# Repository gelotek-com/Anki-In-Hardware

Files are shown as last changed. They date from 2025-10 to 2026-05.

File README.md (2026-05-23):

# Physical Anki Device

Building a physical flashcard device inspired by **Anki** and **spaced repetition**.

## YouTube Series
Watch the full project here:  
🎥 https://www.youtube.com/playlist?list=PLZI8gkIZC2W3yhb4EUrMZ4vrkucjjzuon
## My website
My website for more details:
https://gelotek.com/AIH/

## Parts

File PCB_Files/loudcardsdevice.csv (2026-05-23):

Reference | Qty | Value | Footprint | Manufacturer | MPN | Supplier | Supplier Part
TP1,TP2,TP3,TP4,TP5,TP6,TP7,TP8,TP9,TP10,TP11 | 11 | TestPoint | TestPoint:TestPoint_Pad_1.0x1.0mm
C1,C2,C5,C6,C8,C9,C10,C15,C27,C29 | 10 | 0.1u | Capacitor_SMD:C_0603_1608Metric | Walsin | 0603B104K250CT | LCSC | C83054
U5 | 1 | AMS1117-3.3 | Package_TO_SOT_SMD:SOT-223-3_TabPin2 | Advanced Monolithic Systems | AMS1117-3.3 | LCSC | C6186
U1 | 1 | ESP32-C3-WROOM-02 | RF_Module:ESP32-C3-WROOM-02 | ESPRESSIF | ESP32-C3-WROOM-02-H4 | LCSC | C2944070
R5,R14,R15,R22,R23,R24 | 6 | 5.1k | Resistor_SMD:R_0603_1608Metric | FOJAN | FRC0603F5101TS | LCSC | C2907044
J3 | 1 | USB_C_Receptacle_PowerOnly_6P | Connector_USB:USB_C_Receptacle_GCT_USB4125-xx-x-0190_6P_TopMnt_Horizontal | GCT | USB4125-GF-A-0190 | LCSC | C5246813
FB1 | 1 | 600Ω @ 100MHzSize 0805 preferred for audio rails. | Inductor_SMD:L_0805_2012Metric | muRata | BLM21PG221SN1D | LCSC | C85840
C3,C19,C20,C21,C22,C24,C25 | 7 | 1u | Capacitor_SMD:C_0603_1608Metric | Samsung Electro-Mechanics | CL10A105KO8NNNC | LCSC | C1592
C4,C7,C13,C14,C17,C26,C28 | 7 | 10u | Capacitor_SMD:C_0603_1608Metric | Samsung Electro-Mechanics | CL10A106MQ8NNNC | LCSC | C1691
C11,C12,C23 | 3 | 2.2u | Capacitor_SMD:C_0603_1608Metric | Samsung Electro-Mechanics | CL10A225KQ8NNNC | LCSC | C71000
D5 | 1 | TVS 5V ESD Protection | Diode_SMD:D_SOD-323F | SEMTECH | SD05.TCT | LCSC | C85201
J2 | 1 | AudioJack4 | Connector_Audio:Jack_3.5mm_PJ320D_Horizontal | SHOU HAN | PJ-320D | LCSC | C431535
SW1,SW2,SW3,SW4,SW5 | 5 | SW_Push | Button_Switch_THT:SW_PUSH_6mm | SHOU HAN | TS665CJ | LCSC | C393938
U3 | 1 | PCM5102A | Package_SO:TSSOP-20_4.4x6.5mm_P0.65mm | TI | PCM5102APWR | LCSC | C107671
U4 | 1 | TPA6132A2RTE | Package_DFN_QFN:WQFN-16-1EP_3x3mm_P0.5mm_EP1.6x1.6mm_ThermalVias | TI | TPA6132A2RTER | LCSC | C69901
R19,R20 | 2 | 470 | Resistor_SMD:R_0603_1608Metric | UNI-ROYAL | 0603WAF4700T5E | LCSC | C23179
C16,C18 | 2 | 2.2n | Capacitor_SMD:C_0603_1608Metric | Walsin | 0603B222K500CT | LCSC | C93190
U2 | 1 | W25Q128JVS | Package_SO:SOIC-8_5.3x5.3mm_P1.27mm | Winbond | W25Q128JVSIQ | LCSC | C97521
J1 | 1 | Conn_01x04 | Connector_PinHeader_2.54mm:PinHeader_1x04_P2.54mm_Vertical | XFCN | PZ254V-11-04P | LCSC | C2691448
R1,R2,R3,R4,R10,R11,R12 | 7 | 10k | Resistor_SMD:R_0603_1608Metric | YAGEO | RC0603FR-0710KL | LCSC | C98220
R6,R7,R8,R9 | 4 | 50 | Resistor_SMD:R_0603_1608Metric | YAGEO | RT0603BRE0750RL | LCSC | C849792
R13,R21 | 2 | 100k | Resistor_SMD:R_0603_1608Metric | YAGEO | RC0603FR-07100KL | LCSC | C14675
R16,R17,R18 | 3 | 22 | Resistor_SMD:R_0603_1608Metric | YAGEO | RC0603FR-0722RL | LCSC | C107701
D1,D2,D3,D4 | 4 | LED | LED_SMD:LED_0603_1608Metric | YONGYUTAI | YLED0603R | LCSC | C19171390

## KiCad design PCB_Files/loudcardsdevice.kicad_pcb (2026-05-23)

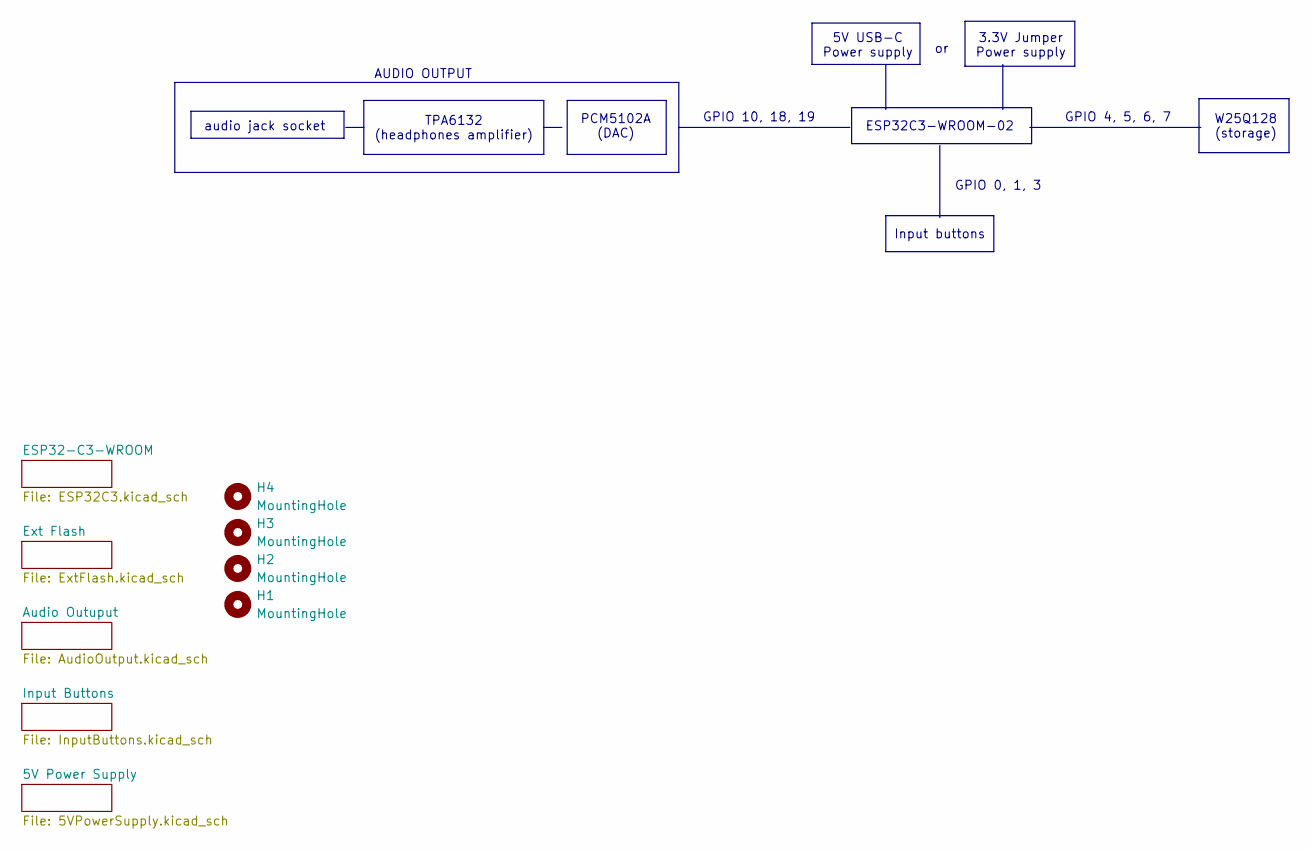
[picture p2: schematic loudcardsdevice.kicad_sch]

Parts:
H1, H2, H3, H4: MountingHole; MountingHole_2.1mm

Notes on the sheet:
ESP32C3-WROOM-02
GPIO 10, 18, 19
PCM5102A (DAC)
3.3V Jumper Power supply
GPIO 0, 1, 3
5V USB-C Power supply
AUDIO OUTPUT
TPA6132 (headphones amplifier)
Input buttons
W25Q128 (storage)
GPIO 4, 5, 6, 7
audio jack socket

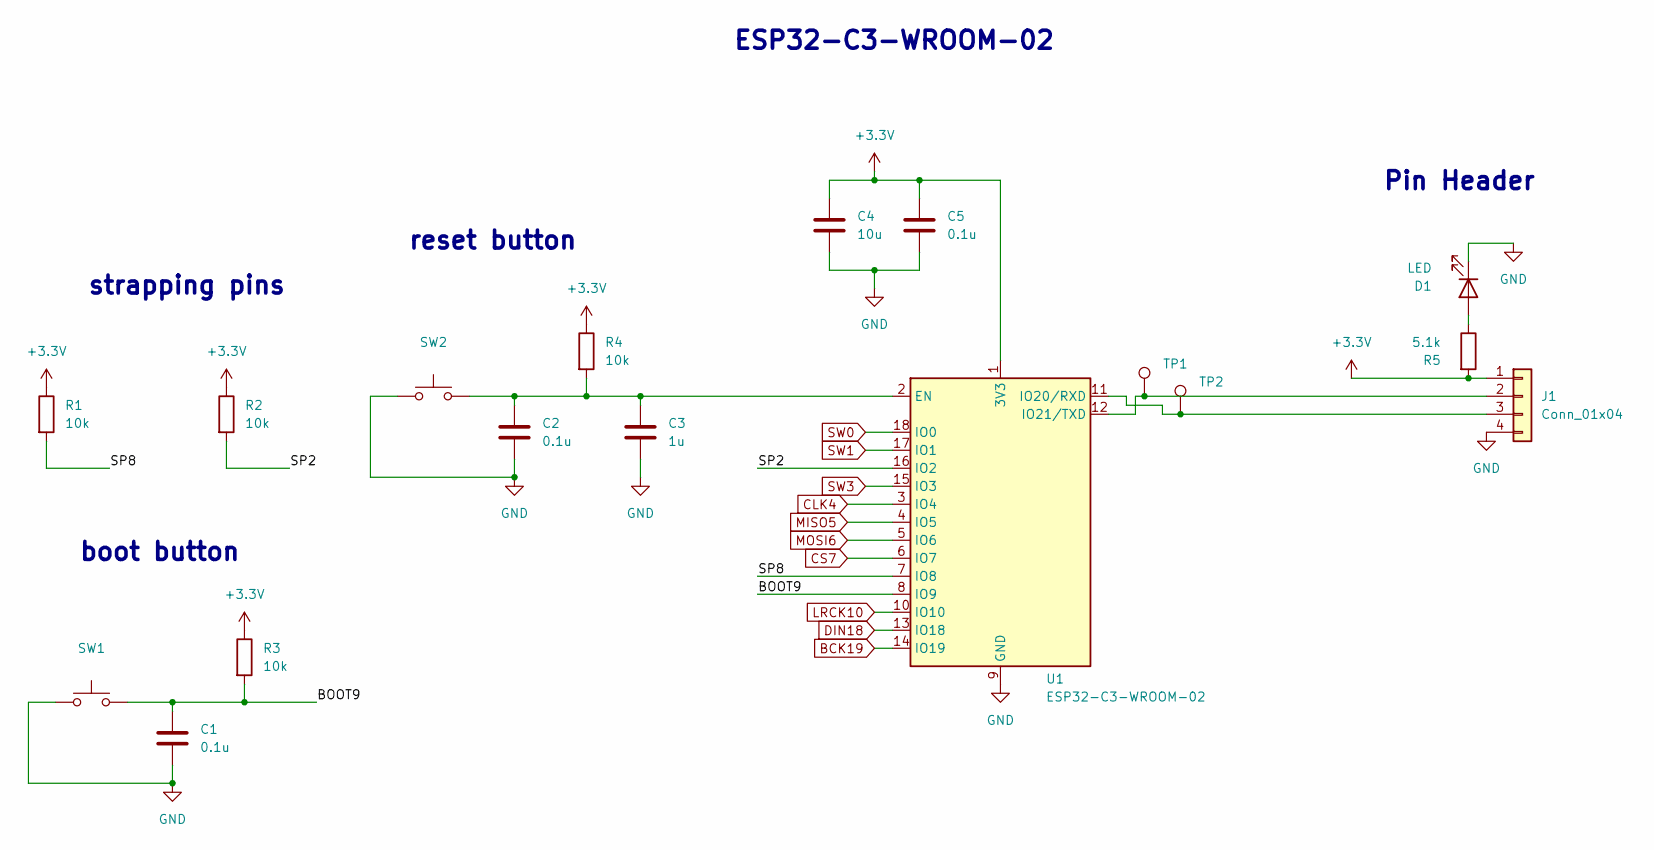
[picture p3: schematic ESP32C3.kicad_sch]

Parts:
C1, C2, C5: 0.1u; C_0603_1608Metric; MPN 0603B104K250CT
C3: 1u; C_0603_1608Metric; MPN CL10A105KO8NNNC
C4: 10u; C_0603_1608Metric; MPN CL10A106MQ8NNNC
D1: LED; LED_0603_1608Metric; MPN YLED0603R
J1: Conn_01x04; PinHeader_1x04_P2.54mm_Vertical; MPN PZ254V-11-04P
R1, R2, R3, R4: 10k; R_0603_1608Metric; MPN RC0603FR-0710KL
R5: 5.1k; R_0603_1608Metric; MPN FRC0603F5101TS
SW1, SW2: SW_Push; SW_PUSH_6mm; MPN TS665CJ
TP1, TP2: TestPoint; TestPoint_Pad_1.0x1.0mm
U1: ESP32-C3-WROOM-02; MPN ESP32-C3-WROOM-02-H4

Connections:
+3.3V: C4.1, C5.1, J1.1, R1.1, R2.1, R3.1, R4.1, R5.2, U1.1 (3V3); also elsewhere on the board
/ESP32-C3-WROOM/BOOT9: C1.1, R3.2, SW1.2, U1.8 (IO9)
/ESP32-C3-WROOM/SP2: R2.2, U1.16 (IO2)
/ESP32-C3-WROOM/SP8: R1.2, U1.7 (IO8)
BCK19: U1.14 (IO19); also elsewhere on the board
CLK4: U1.3 (IO4); also elsewhere on the board
CS7: U1.6 (IO7); also elsewhere on the board
DIN18: U1.13 (IO18); also elsewhere on the board
GND: C1.2, C2.2, C3.2, C4.2, C5.2, D1.1 (K), J1.4, SW1.1, SW2.1, U1.9 (GND), U1.19 (GND); also elsewhere on the board
LRCK10: U1.10 (IO10); also elsewhere on the board
MISO5: U1.4 (IO5); also elsewhere on the board
MOSI6: U1.5 (IO6); also elsewhere on the board
unnamed: D1.2 (A), R5.1
unnamed: J1.2, TP1.1, U1.12 (IO21/TXD)
unnamed: J1.3, TP2.1, U1.11 (IO20/RXD)
unnamed: C2.1, C3.1, R4.2, SW2.2, U1.2 (EN)
SW0: U1.18 (IO0); also elsewhere on the board
SW1: U1.17 (IO1); also elsewhere on the board
SW3: U1.15 (IO3); also elsewhere on the board

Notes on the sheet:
strapping pins
boot button
Pin Header
reset button
ESP32-C3-WROOM-02

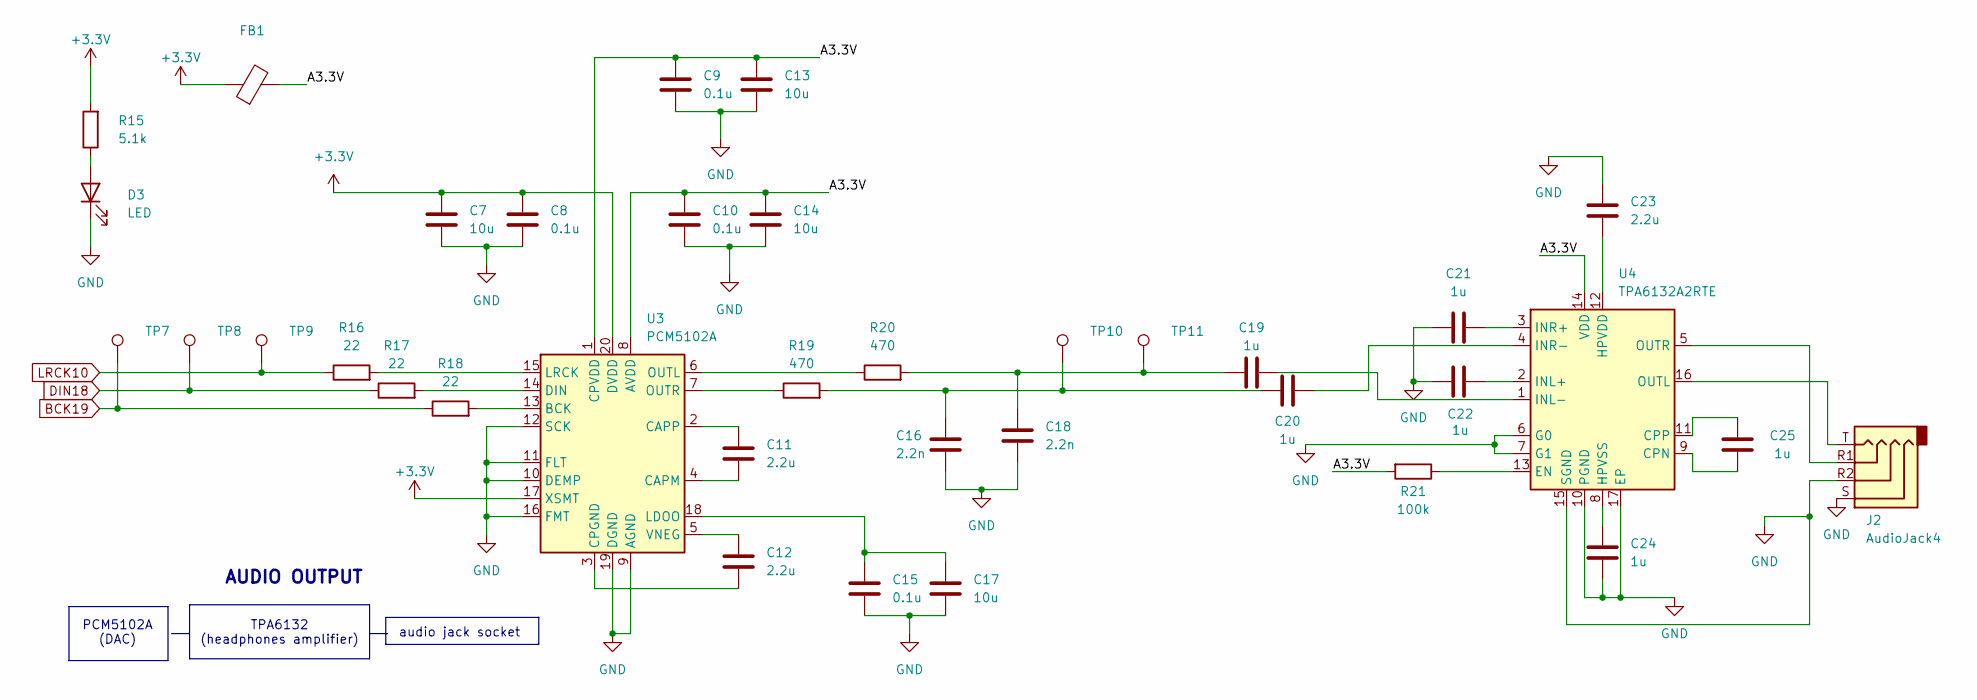
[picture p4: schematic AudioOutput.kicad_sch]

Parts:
C7, C13, C14, C17: 10u; C_0603_1608Metric; MPN CL10A106MQ8NNNC
C8, C9, C10, C15: 0.1u; C_0603_1608Metric; MPN 0603B104K250CT
C11, C12, C23: 2.2u; C_0603_1608Metric; MPN CL10A225KQ8NNNC
C16, C18: 2.2n; C_0603_1608Metric; MPN 0603B222K500CT
C19, C20, C21, C22, C24, C25: 1u; C_0603_1608Metric; MPN CL10A105KO8NNNC
D3: LED; LED_0603_1608Metric; MPN YLED0603R
FB1: 600Ω @ 100MHzSize 0805 preferred for audio rails.; L_0805_2012Metric; MPN BLM21PG221SN1D
J2: AudioJack4; Jack_3.5mm_PJ320D_Horizontal; MPN PJ-320D
R15: 5.1k; R_0603_1608Metric; MPN FRC0603F5101TS
R16, R17, R18: 22; R_0603_1608Metric; MPN RC0603FR-0722RL
R19, R20: 470; R_0603_1608Metric; MPN 0603WAF4700T5E
R21: 100k; R_0603_1608Metric; MPN RC0603FR-07100KL
TP7, TP8, TP9, TP10, TP11: TestPoint; TestPoint_Pad_1.0x1.0mm
U3: PCM5102A; TSSOP-20_4.4x6.5mm_P0.65mm; MPN PCM5102APWR
U4: TPA6132A2RTE; WQFN-16-1EP_3x3mm_P0.5mm_EP1.6x1.6mm_ThermalVias; MPN TPA6132A2RTER

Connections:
+3.3V: C7.1, C8.1, FB1.1, R15.2, U3.17 (XSMT), U3.20 (DVDD); also elsewhere on the board
/Audio Outuput/A3.3V: C9.1, C10.1, C13.1, C14.1, FB1.2, R21.2, U3.1 (CPVDD), U3.8 (AVDD), U4.14 (VDD)
BCK19: R18.1, TP7.1; also elsewhere on the board
DIN18: R17.1, TP8.1; also elsewhere on the board
GND: C7.2, C8.2, C9.2, C10.2, C13.2, C14.2, C15.2, C16.2, C17.2, C18.2, C21.1, C22.1, C23.2, C24.1, D3.1 (K), J2.R2, J2.S, U3.9 (AGND), U3.10 (DEMP), U3.11 (FLT), U3.12 (SCK), U3.16 (FMT), U3.19 (DGND), U4.6 (G0), U4.7 (G1), U4.10 (PGND), U4.15 (SGND), U4.17 (EP); also elsewhere on the board
LRCK10: R16.1, TP9.1; also elsewhere on the board
unnamed: C16.1, C20.1, R19.2, TP10.1
unnamed: C18.1, C19.1, R20.2, TP11.1
unnamed: D3.2 (A), R15.1
unnamed: R18.2, U3.13 (BCK)
unnamed: C11.2, U3.4 (CAPM)
unnamed: C11.1, U3.2 (CAPP)
unnamed: C12.2, U3.3 (CPGND)
unnamed: R17.2, U3.14 (DIN)
unnamed: C15.1, C17.1, U3.18 (LDOO)
unnamed: R16.2, U3.15 (LRCK)
unnamed: R20.1, U3.6 (OUTL)
unnamed: R19.1, U3.7 (OUTR)
unnamed: C12.1, U3.5 (VNEG)
unnamed: C25.2, U4.9 (CPN)
unnamed: C25.1, U4.11 (CPP)
unnamed: R21.1, U4.13 (EN)
unnamed: C23.1, U4.12 (HPVDD)
unnamed: C24.2, U4.8 (HPVSS)
unnamed: C22.2, U4.2 (INL+)
unnamed: C19.2, U4.1 (INL-)
unnamed: C21.2, U4.3 (INR+)
unnamed: C20.2, U4.4 (INR-)
unnamed: J2.T, U4.16 (OUTL)
unnamed: J2.R1, U4.5 (OUTR)

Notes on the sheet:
audio jack socket
PCM5102A (DAC)
TPA6132 (headphones amplifier)
AUDIO OUTPUT

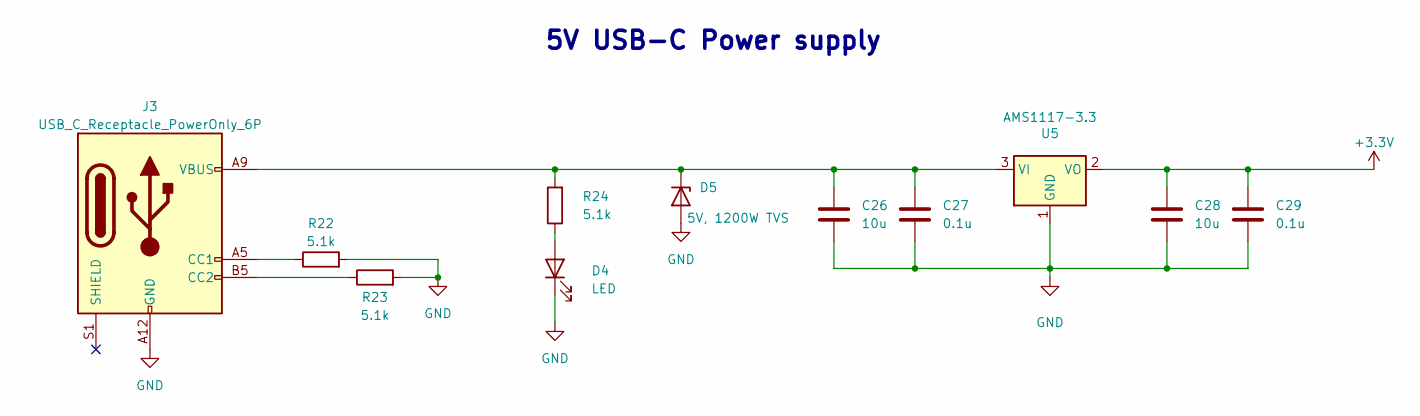
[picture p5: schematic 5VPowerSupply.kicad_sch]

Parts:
C26, C28: 10u; C_0603_1608Metric; MPN CL10A106MQ8NNNC
C27, C29: 0.1u; C_0603_1608Metric
D4: LED; LED_0603_1608Metric; MPN YLED0603R
D5: 5V, 1200W TVS; D_SOD-323F; MPN SD05.TCT
J3: USB_C_Receptacle_PowerOnly_6P; USB_C_Receptacle_GCT_USB4125-xx-x-0190_6P_TopMnt_Horizontal; MPN USB4125-GF-A-0190
R22, R23, R24: 5.1k; R_0603_1608Metric; MPN FRC0603F5101TS
U5: AMS1117-3.3; SOT-223-3_TabPin2; MPN AMS1117-3.3

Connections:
+3.3V: C28.1, C29.1, U5.2 (VO); also elsewhere on the board
GND: C26.2, C27.2, C28.2, C29.2, D4.1 (K), D5.2 (A), J3.A12 (GND), J3.B12 (GND), R22.2, R23.2, U5.1 (GND); also elsewhere on the board
unnamed: D4.2 (A), R24.1
unnamed: C26.1, C27.1, D5.1 (K), J3.A9 (VBUS), J3.B9 (VBUS), R24.2, U5.3 (VI)
unnamed: J3.A5 (CC1), R22.1
unnamed: J3.B5 (CC2), R23.1

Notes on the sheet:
5V USB-C Power supply

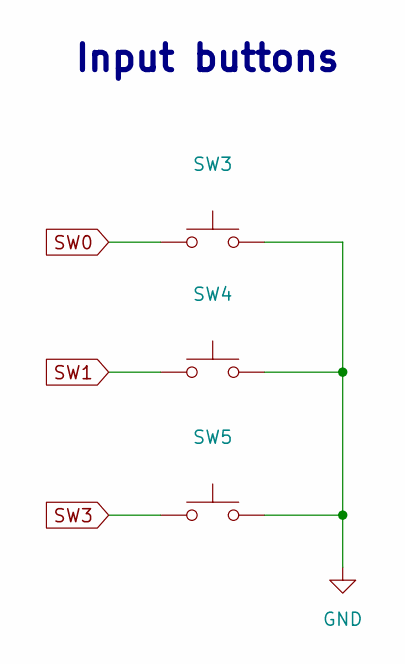
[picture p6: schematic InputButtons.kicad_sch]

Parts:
SW3, SW4, SW5: SW_Push; SW_PUSH_6mm; MPN TS665CJ

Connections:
GND: SW3.2, SW4.2, SW5.2; also elsewhere on the board
SW0: SW3.1; also elsewhere on the board
SW1: SW4.1; also elsewhere on the board
SW3: SW5.1; also elsewhere on the board

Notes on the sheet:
Input buttons

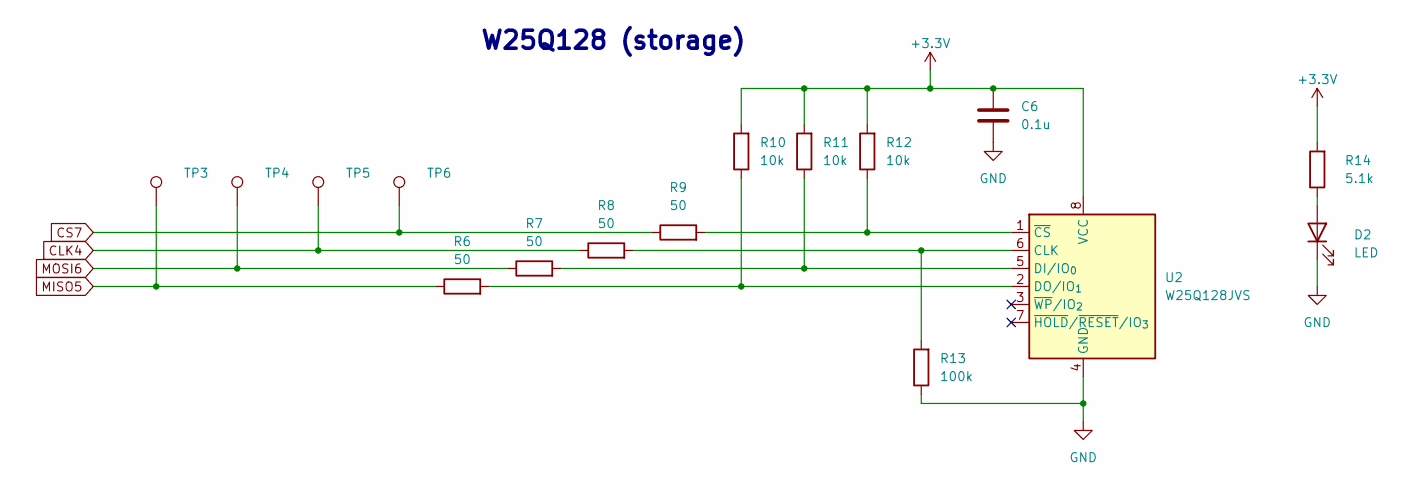
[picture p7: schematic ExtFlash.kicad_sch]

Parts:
C6: 0.1u; C_0603_1608Metric; MPN 0603B104K250CT
D2: LED; LED_0603_1608Metric; MPN YLED0603R
R6, R7, R8, R9: 50; R_0603_1608Metric; MPN RT0603BRE0750RL
R10, R11, R12: 10k; R_0603_1608Metric; MPN RC0603FR-0710KL
R13: 100k; R_0603_1608Metric; MPN RC0603FR-07100KL
R14: 5.1k; R_0603_1608Metric; MPN FRC0603F5101TS
TP3, TP4, TP5, TP6: TestPoint; TestPoint_Pad_1.0x1.0mm
U2: W25Q128JVS; SOIC-8_5.3x5.3mm_P1.27mm; MPN W25Q128JVSIQ

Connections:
+3.3V: C6.1, R10.2, R11.2, R12.2, R14.2, U2.8 (VCC); also elsewhere on the board
CLK4: R8.1, TP5.1; also elsewhere on the board
CS7: R9.1, TP6.1; also elsewhere on the board
GND: C6.2, D2.1 (K), R13.1, U2.4 (GND); also elsewhere on the board
MISO5: R6.1, TP3.1; also elsewhere on the board
MOSI6: R7.1, TP4.1; also elsewhere on the board
unnamed: D2.2 (A), R14.1
unnamed: R8.2, R13.2, U2.6 (CLK)
unnamed: R7.2, R11.1, U2.5 (DI/IO_{0})
unnamed: R6.2, R10.1, U2.2 (DO/IO_{1})
unnamed: R9.2, R12.1, U2.1 (~CS)

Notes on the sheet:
W25Q128 (storage)

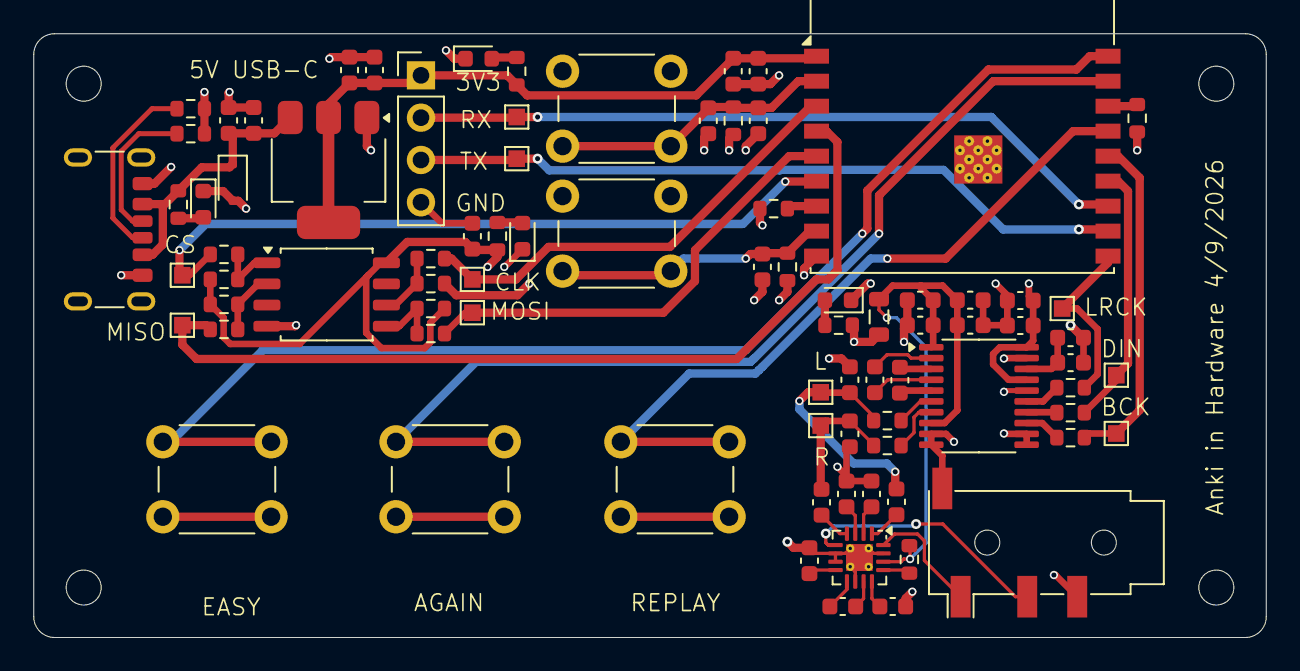
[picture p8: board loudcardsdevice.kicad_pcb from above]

Board: 4 copper layers, 74.0 x 36.2 mm, 87 parts (0 on the bottom side), 53 nets.

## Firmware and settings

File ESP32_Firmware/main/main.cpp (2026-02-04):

#include <stdio.h>
#include <string>

#include "freertos/FreeRTOS.h"
#include "freertos/task.h"

#include "esp_log.h"
#include "nvs_flash.h"

#include "driver/gpio.h"

#include <ArduinoJson.h>

#include "wifi_setup.h"
#include "setup_buttons.h"
#include "http_setup.h"
#include "audio_setup.h"
#include "ext_flash.h"

static const char *TAG = "MAIN";


extern "C" void app_main(void)
{
    // Initialize NVS (required for WiFi, HTTP, etc.)
    esp_err_t ret = nvs_flash_init();
    if (ret == ESP_ERR_NVS_NO_FREE_PAGES || ret == ESP_ERR_NVS_NEW_VERSION_FOUND) {
        nvs_flash_erase();
        nvs_flash_init();
    }

    ESP_LOGI(TAG, "System starting");

    // Hardware setup
    setupButtons();

    vTaskDelay(pdMS_TO_TICKS(1000));

    setupAudio(); // setup audio  + extflash
    setupWiFi();

    /*
    clearIntFiles();

    vTaskDelay(pdMS_TO_TICKS(1000));

    DownloadSpecificAudio("/response.wav");
    DownloadSpecificAudio("/start.wav");
    DownloadSpecificAudio("/clear.wav");
    DownloadSpecificAudio("/download.wav");
    DownloadSpecificAudio("/downloading.wav");
    DownloadSpecificAudio("/end.wav");
    */

    // Startup audio
    playAudio("/start.wav", "/littlefs");
    playAudio("/response.wav", "/littlefs");

    // Wait for user action
    waitForButton("Press YELLOW to start or BLUE to download the audio files");

    // Get cards from server
    std::string cardData = HTTPboot();

    // JSON for HTTP output
    JsonDocument easeDoc;
    JsonArray easeArray = easeDoc["results"].to<JsonArray>();

    // JSON for FlashCards
    JsonDocument doc;
    DeserializationError err = deserializeJson(doc, cardData);
    if (err) {
        ESP_LOGE(TAG, "JSON parse failed: %s", err.c_str());
        return;
    }

    JsonArray cards = doc["cards"].as<JsonArray>();

    // Download all audio files
    downloadAllAudio_ext(cards);

    playAudio("/download.wav", "/littlefs");

    // Study session
    for (JsonObject card : cards) {
        int64_t cardId = card["id"].as<long long>();
        std::string front = card["front"].as<std::string>();
        std::string back  = card["back"].as<std::string>();

        if (checkAudioFiles_ext(cardId)) {
            ESP_LOGI(TAG, "---- Next card ----");
            ESP_LOGI(TAG, "Front: %s", front.c_str());

            // Front
            ESP_LOGI(TAG, "Press START to see the back.");
            playFrontAudio(button3Pin, button1Pin, cardId);

            // Back
            ESP_LOGI(TAG, "Back: %s", back.c_str());
            ESP_LOGI(TAG, "Decide");

            int ease = playBackAudio(
                button1Pin,
                button2Pin,
                button3Pin,
                cardId
            );

            // Store result
            JsonObject r = easeArray.add<JsonObject>();
            r["card_id"] = cardId;
            r["ease"] = ease;
        }
    }

    // Send results back
    std::string jsonOut;
    serializeJson(easeDoc, jsonOut);

    ESP_LOGI(TAG, "Result JSON: %s", jsonOut.c_str());
    HTTPout(jsonOut);

    // Session complete
    playAudio("/end.wav", "/littlefs");
    ESP_LOGI(TAG, "Study session complete.");


    // app_main should not exit
    while (true) {
        vTaskDelay(pdMS_TO_TICKS(1000));
    }
}

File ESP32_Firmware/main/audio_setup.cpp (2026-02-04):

#include "audio_setup.h"
#include "ext_flash.h"

#include <stdint.h>
#include <stdlib.h>
#include <stdio.h>
#include <string>

#include "freertos/FreeRTOS.h"
#include "freertos/task.h"

#include "esp_log.h"
//#include "esp_vfs_littlefs.h"
#include "esp_vfs.h"
#include "esp_littlefs.h"

//#include "driver/ledc.h"
#include "driver/gpio.h"
#include "esp_rom_sys.h"

#include "driver/i2s_std.h"


#define EXAMPLE_STD_BCLK_IO1   GPIO_NUM_21
#define EXAMPLE_STD_WS_IO1     GPIO_NUM_10
#define EXAMPLE_STD_DOUT_IO1   GPIO_NUM_20
#define EXAMPLE_STD_DIN_IO1    GPIO_NUM_NC

#define EXAMPLE_BUFF_SIZE               2048
static i2s_chan_handle_t                tx_chan; 

static const char *TAG = "AUDIO";


void playAudio(const std::string &path, const std::string &storage)
{
    //printf("Playback started\n");
    std::string fullPath = storage + path;
    FILE *f = fopen(fullPath.c_str(), "rb");
    if (!f) {
        printf("Failed to open audio file\n");
        vTaskDelete(NULL);
        return;
    }

    fseek(f, 44, SEEK_SET);

    uint8_t *buf = (uint8_t *)malloc(EXAMPLE_BUFF_SIZE);
    if (!buf) {
        fclose(f);
        vTaskDelete(NULL);
        return;
    }

    ESP_ERROR_CHECK(i2s_channel_enable(tx_chan));

    size_t bytes_read = 0;
    
    while ((bytes_read = fread(buf, 1, EXAMPLE_BUFF_SIZE, f)) > 0) {
        //printf("Read %d bytes\n", bytes_read);
        size_t written = 0;
        esp_err_t err = i2s_channel_write(tx_chan, buf, bytes_read, &written, portMAX_DELAY);
        //printf("Written %d bytes\n", written);
        if (err != ESP_OK) {
            printf("I2S write failed: %d\n", err);
            break;
        }
    }

    //printf("Playback finished\n");
    i2s_channel_disable(tx_chan);
    free(buf);
    fclose(f);
    ESP_LOGI(TAG, "Done playing: %s", path.c_str());
}

void i2s_example_init_std_simplex(void)
{
    i2s_chan_config_t tx_chan_cfg = I2S_CHANNEL_DEFAULT_CONFIG(I2S_NUM_AUTO, I2S_ROLE_MASTER);
    ESP_ERROR_CHECK(i2s_new_channel(&tx_chan_cfg, &tx_chan, NULL));

    i2s_std_config_t tx_std_cfg = {
        .clk_cfg  = I2S_STD_CLK_DEFAULT_CONFIG(16000),
        .slot_cfg = I2S_STD_PHILIPS_SLOT_DEFAULT_CONFIG(I2S_DATA_BIT_WIDTH_16BIT, I2S_SLOT_MODE_STEREO),
        .gpio_cfg = {
            .mclk = I2S_GPIO_UNUSED,
            .bclk = EXAMPLE_STD_BCLK_IO1,
            .ws   = EXAMPLE_STD_WS_IO1,
            .dout = EXAMPLE_STD_DOUT_IO1,
            .din  = EXAMPLE_STD_DIN_IO1,
            .invert_flags = {
                .mclk_inv = false,
                .bclk_inv = false,
                .ws_inv   = false,
            },
        },
    };
    ESP_ERROR_CHECK(i2s_channel_init_std_mode(tx_chan, &tx_std_cfg));
}

void setupAudio()
{
    vTaskDelay(pdMS_TO_TICKS(200));

    mount_extflash(); //ADDED

    vTaskDelay(pdMS_TO_TICKS(200));

    ESP_LOGI(TAG, "Initializing LittleFS...");
    vTaskDelay(pdMS_TO_TICKS(200));

    esp_vfs_littlefs_conf_t conf = {};
    conf.base_path = "/littlefs";
    conf.partition_label = "storage"; //littlefs
    conf.format_if_mount_failed = true;
    conf.read_only = false;
    conf.grow_on_mount = false;
    conf.dont_mount = false;


    esp_err_t ret = esp_vfs_littlefs_register(&conf);
    if (ret != ESP_OK) {
        ESP_LOGE(TAG, "LittleFS mount failed (%s)", esp_err_to_name(ret));
        while (true) vTaskDelay(portMAX_DELAY);
    }

    ESP_LOGI(TAG, "LittleFS OK!");

    i2s_example_init_std_simplex();
}


void playFrontAudio(int button3Pin, int button1Pin, int64_t cardId)
{
    std::string file = "/" + std::to_string(cardId) + "_front.wav";
    playAudio(file, "/extflash");

    while (true) {
        if (gpio_get_level((gpio_num_t)button3Pin) == 0) {
            playAudio(file, "/extflash");
            vTaskDelay(pdMS_TO_TICKS(300));
        }
        if (gpio_get_level((gpio_num_t)button1Pin) == 0) {
            vTaskDelay(pdMS_TO_TICKS(300));
            break;
        }
        vTaskDelay(pdMS_TO_TICKS(50));
    }
}

int playBackAudio(int button1Pin, int button2Pin, int button3Pin, int64_t cardId)
{
    std::string file = "/" + std::to_string(cardId) + "_back.wav";
    playAudio(file, "/extflash");

    while (true) {
        if (gpio_get_level((gpio_num_t)button3Pin) == 0) {
            playAudio(file, "/extflash");
            vTaskDelay(pdMS_TO_TICKS(300));
        }
        if (gpio_get_level((gpio_num_t)button1Pin) == 0) {
            vTaskDelay(pdMS_TO_TICKS(300));
            return 1;
        }
        if (gpio_get_level((gpio_num_t)button2Pin) == 0) {
            vTaskDelay(pdMS_TO_TICKS(300));
            return 4;
        }
        vTaskDelay(pdMS_TO_TICKS(50));
    }
}


bool checkAudioFiles_ext(int64_t cardId)
{
    std::string front = "/extflash/" + std::to_string(cardId) + "_front.wav";
    std::string back  = "/extflash/" + std::to_string(cardId) + "_back.wav";

    FILE *f1 = fopen(front.c_str(), "r");
    FILE *f2 = fopen(back.c_str(), "r");

    if (f1 && f2) {
        fclose(f1);
        fclose(f2);
        ESP_LOGI(TAG, "Audio files exist");
        return true;
    }

    if (f1) fclose(f1);
    if (f2) fclose(f2);

    ESP_LOGW(TAG, "Audio files do not exist, this card cannot be studied");
    return false;
}


void clearExtFiles(){
    DIR *dir = opendir("/extflash");
    if (!dir) return;

    struct dirent *entry;
    while ((entry = readdir(dir)) != nullptr) {
        std::string name = entry->d_name;
        std::string path = "/extflash/" + name;
        ESP_LOGI(TAG, "Removing: %s", path.c_str());
        unlink(path.c_str());
        
    }

    closedir(dir);
    ESP_LOGI(TAG, "Finished clearing External Flash");
}

void clearIntFiles (){
    DIR *dir = opendir("/littlefs");
    if (!dir) return;

    struct dirent *entry;
    while ((entry = readdir(dir)) != nullptr) {
        std::string name = entry->d_name;
        std::string path = "/littlefs/" + name;
        ESP_LOGI(TAG, "Removing: %s", path.c_str());
        unlink(path.c_str());
        
    }

    closedir(dir);
    ESP_LOGI(TAG, "Finished clearing LittleFS");
}

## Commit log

2026-02-04 Part 10
    [partitions.csv]
2026-05-23 PCB files
    [5VPowerSupply.kicad_sch, AudioOutput.kicad_sch, ESP32C3.kicad_sch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]
